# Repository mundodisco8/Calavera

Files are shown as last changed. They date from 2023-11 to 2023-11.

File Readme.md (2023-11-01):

# Calavera Badge

We wanted to run a "lunch and learn" day at the company I used to work about soldering. I always liked [Protopic's Day of the Geek Soldering Badge](https://www.proto-pic.co.uk/day-of-the-geek-badge/), but it only turns two LEDs on when you slide the battery, and I thought that my mates would need a bit more than a couple of LEDs to be able to say that they know how to solder, so I thought on modifying. I checked around but it seems the project is not open source, so I decided to ~~blatantly copy~~ get inspired by them.

<p float="center">
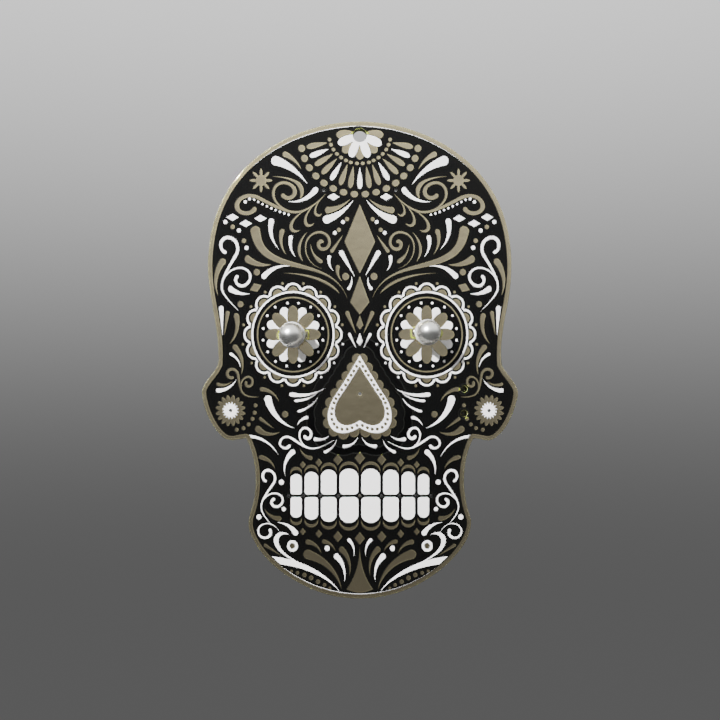
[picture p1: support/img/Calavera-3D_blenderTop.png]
  
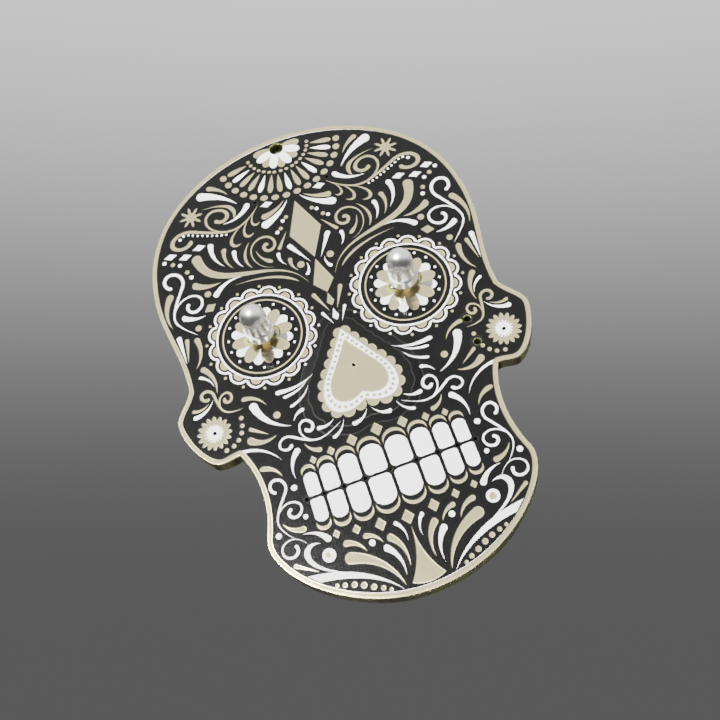
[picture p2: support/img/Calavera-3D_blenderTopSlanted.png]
  
</p>

<p float="center">
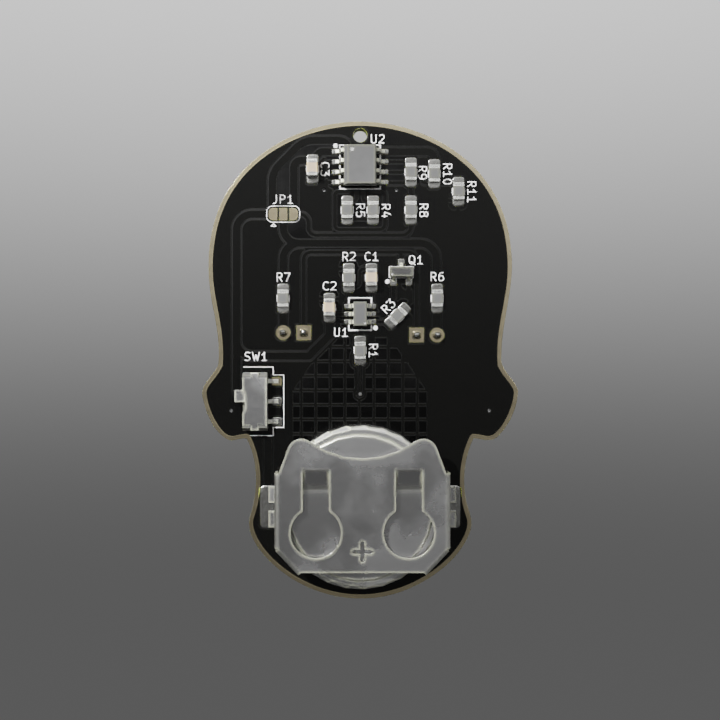
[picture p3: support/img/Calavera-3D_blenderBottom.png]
  
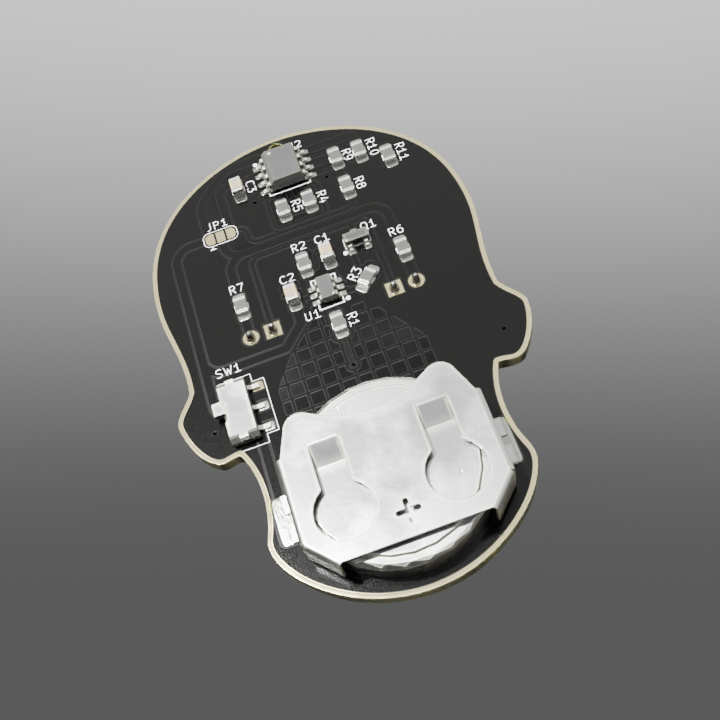
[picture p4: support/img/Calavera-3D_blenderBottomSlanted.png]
  
</p>

So here I was, thinking how to improve it, if I should go nuts or keep it simple. Danny, what should I do? should I go simple?

Danny says nope!

As I wanted to do a bit more, I decided to add two features:

* A way to turn it on and off. I thought adding a slider switch (and that would be a terrific idea in any case). I had never experimented with cap touch, so I thought in giving it a go.
* Add a "breathe" effect to the LEDs.

The schematic includes instructions on pretty much everything, so I recommend checking it. You can choose how challenging you want it to be, from "slide battery to get LEDs on" to "cap touch with breathe effect" and all the possibilities in between.

Turns out the badge is a bit overkill. It took me around 30 minutes to do one, and a colleague that has never soldered took something around 2-3h to finish it.

ups!

I was testing Cadlab when I was doing this project, you can view this project [here](https://cadlab.io/project/2044).

## Variants

I wanted to experiment with plated PCB borders. It gives it a very nice touch, but they are expensive, so you might want to make a cheaper version. There are two "footprints" for the soldermask "part", so you can choose to have the plated border or not. You might want to run the "Border" variant even without plated borders to get a nice copper outline, too. In any case, this board is yelling to be finished in ENIG, so please expend some money on that. Is not that expensive.

## The support folder

You can find the original SVG used for the art, as well as some SVGs I used to

## Known Issues / To Do:

* Tweak the cap touch pad / circuitry. Right now the cap touch feature is not very reliable. The values are the standard ones provided in the datasheet. A bit of experimenting could make it more reliable, but who has time for that, right?

## Acknowledgements

* [Terayza](https://github.com/Terayza) for her invaluable help.
* Protopic for doing their Day of the Geek soldering badge. Theirs is infinitely nicer than mine.
* The graphic on the top silkscreen / soldermask is taken from [Freepik](www.freepik.com).
* [The SVG2Shenzhen plugin.](https://github.com/badgeek/svg2shenzhen)
* My mate Danny DV, for being so nice and lending his image for this readme.

## Changelog

### v0.3.1-RC1 - 30th October 2023

* Moved the project to KiCad 7, and took the opportunity to tweak some footprints and the art.
* Made the touch area a bit bigger.

### v0.3.0 (untested, never produced) - 28th October 2022

Slightly improved version.

* Changed the double NMOS for a single one. Package is the "same" than v0.2.0 (SOT23), but having only 3 pins should make it way simpler to solder. We don't drive current, so we don't need two transistors.
* Cleaned the track layout
* Added a switch so you can fully turn it off when not in use.
* Added a couple of good practices from [ST's AN4312](https://www.st.com/resource/en/application_note/dm00087990-design-with-surface-sensors-for-touch-sensing-applications-on-mcus-stmicroelectronics.pdf). Hatched the ground below the pad and made its trace to the sensor thinner. Planes connected to ground which increases the parasitic capacitance on the cap sensor (bad) but it's better than a floating plane as it was before (worse).

### v0.2.0 (untested, never produced) - 10th January 2020

Slightly improved version.

* Cleaned the folder structure. Now all the parts are in the same library, and all the 3D models are relatively referenced to the project path.
* Changed the transistor to a SOT23. Should be easier to solder.
* Increased the track width.
* Made the border slightly thinner, I think? I don't remember. Probably.
* Isolated the ground plane from the copper pour, because I suspect that it will improve the touch response, but I have no idea if it will work.

### v0.1.0 - 23rd September 2019

First version of this board. It works 💃🎉🚀🦼! But not very well 💣🥦...

* Cap touch is hit and miss. I think that the fact that the border is exposed and tied to ground makes that when you hold it, you mess with the electric field. The whole subcircuit might need a makeover.
* The tracks are very thin and can be ripped up by a young padawan.
* The transistor footprint is devilishly difficult to solder even for an experienced Jedi.

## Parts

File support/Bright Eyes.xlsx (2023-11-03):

 |  |  |  | V | 3 | 2.5
R1 | 180000 | 180000 | 200000 | Vtpp | 0.4390243902 | 0.3658536585
R2 | 1200 | 1470 | 1500 | Vttmax | 2.6 | 2.2
R3 | 8200 | 10000 | 10000 | Vtmin | 2.182409342 | 1.782089086
C1 | 0.000022 | 0.000022 | 0.000022
V Bias ratio | 0.80 | 0.80 | 0.80
Vbias @3 | 2.40 | 2.40 | 2.40
Vbias @2.5 | 2.00 | 2.00 | 2.00
Freq | 0.431 | 0.429 | 0.379
Trise | 0.46 | 0.46 | 0.53
Tfall | 1.86 | 1.86 | 2.11
Rbias1 | 2490 | Ratio | 0.80
RBias2 | 10000

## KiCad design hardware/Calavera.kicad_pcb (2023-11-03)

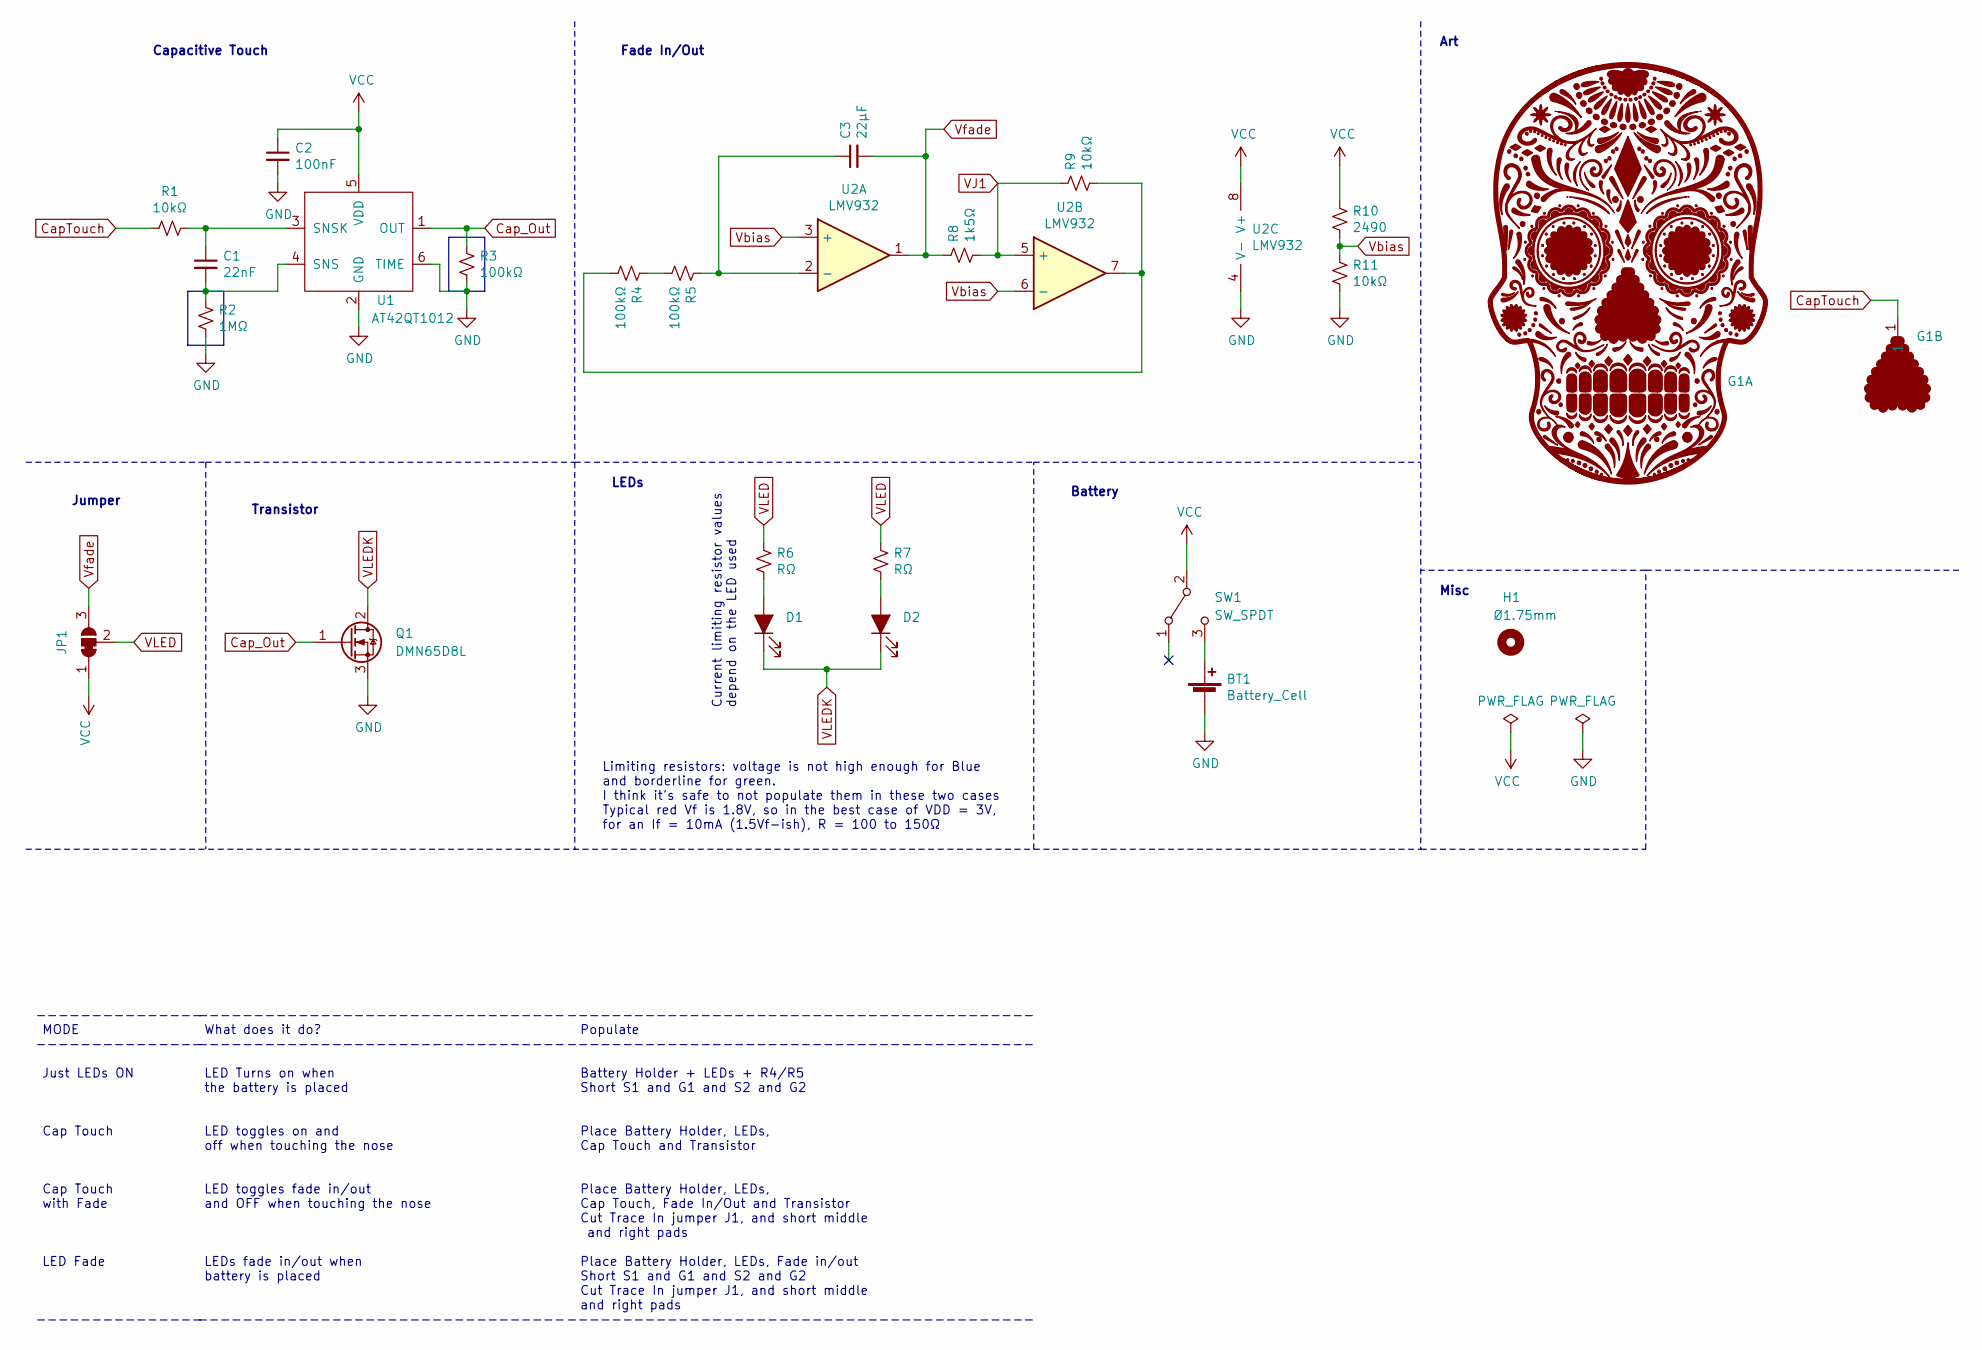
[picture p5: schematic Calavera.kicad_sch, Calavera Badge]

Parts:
BT1: Battery_Cell; CR2032_Keystone_3024; MPN 3034; Digikey PN 36-3034-ND
C1: 22nF; 0805-C_Handsolder; Tolerance X7R; MPN 885342207011; Digikey PN 732-12080-1-ND
C2: 100nF; 0805-C_Handsolder; Tolerance X7R; MPN CL21B104KBCNNNC; Digikey PN 1276-1003-1-ND
C3: 22μF; 0805-C_Handsolder; Tolerance X7R; MPN GRM21BZ71A226ME15L; Digikey PN 490-GRM21BZ71A226ME15LCT-ND
D1, D2: LED_Small_ALT; LED_D3.0mm_ThroughHole; MPN N/A; Digikey PN N/A
G1: Calavera_Art; MPN N/A; Digikey PN N/A
H1: Ø1.75mm; MountingHole_1.75mm; MPN N/A; Digikey PN N/A
JP1: SolderJumper_3_Bridged12; SolderJumper-3_P1.3mm_Bridged12_RoundedPad1.0x1.5mm; MPN N/A; Digikey PN N/A
Q1: DMN65D8L; SOT-23_NMOS_DMN65D8L; MPN DMN65D8L; Digikey PN DMN65D8L-7DICT-ND
R1, R9, R11: 10kΩ; 0805-R_Handsolder; Tolerance ±1%, 1/8W; MPN CR0805-FX-1002ELF; Digikey PN CR0805-FX-1002ELFCT-ND
R2: 1MΩ; 0805-R_Handsolder; Tolerance ±1%, 1/8W; MPN CR0805-FX-1004ELF; Digikey PN CR0805-FX-1004ELFCT-ND
R3, R4, R5: 100kΩ; 0805-R_Handsolder; Tolerance ±1%, 1/8W; MPN CR0805-FX-1003ELF; Digikey PN CR0805-FX-1003ELFCT-ND
R6, R7: RΩ; 0805-R_Handsolder; MPN N/A; Digikey PN N/A
R8: 1k5Ω; 0805-R_Handsolder; Tolerance ±1%, 1/8W; MPN CR0805-FX-1501ELF; Digikey PN CR0805-FX-1501ELFCT-ND
R10: 2490; 0805-R_Handsolder; Tolerance ±1%, 1/8W; MPN CR0805-FX-2491ELF; Digikey PN CR0805-FX-2491ELFCT-ND
SW1: SW_SPDT; Slider_Switch_C&K_AYZ0102AGRLC_SPDT_RightAngle; MPN AYZ0102AGRLC; Digikey PN 401-2012-1-ND
U1: AT42QT1012; SOT23-6-AT42QT1012; MPN AT42QT1012-TSHR; Digikey PN 401-2012-1-ND
U2: LMV932; SOIC-8_Dual_OpAmp_Handsolder; MPN LMV932DR2G; Digikey PN LMV932DR2GOSCT-ND

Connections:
CapTouch: G1.1, R1.2
Cap_Out: Q1.1 (G), R3.1, U1.1 (OUT)
GND: BT1.-, C2.2, Q1.3 (S), R2.2, R3.2, R11.2, U1.2 (GND), U1.6 (TIME), U2.4 (V-)
unnamed: D1.2 (A), R6.2
unnamed: D2.2 (A), R7.2
unnamed: R4.1, R5.2
unnamed: R4.2, R9.2, U2.7
unnamed: BT1.+, SW1.3 (C)
unnamed: C1.2, R2.1, U1.4 (SNS)
unnamed: C1.1, R1.1, U1.3 (SNSK)
unnamed: C3.1, R5.1, U2.2 (-)
VCC: C2.1, JP1.1 (A), R10.1, SW1.2 (B), U1.5 (VDD), U2.8 (V+)
VJ1: R8.2, R9.1, U2.5 (+)
VLED: JP1.2 (C), R6.1, R7.1
VLEDK: D1.1 (K), D2.1 (K), Q1.2 (D)
Vbias: R10.2, R11.1, U2.3 (+), U2.6 (-)
Vfade: C3.2, JP1.3 (B), R8.1, U2.1

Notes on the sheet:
Battery
--------------- MODE --------------- Just LEDs ON Cap Touch Cap Touch with Fade LED Fade ---------------
Capacitive Touch
Misc
Current limiting resistor values depend on the LED used
Jumper
Fade In/Out
Transistor
Limiting resistors: voltage is not high enough for Blue and borderline for green. I think it's safe to not populate them in these two cases Typical red Vf is 1.8V, so in the best case of VDD = 3V, for an If = 10mA (1.5Vf-ish), R = 100 to 150Ω
--------------------------------- What does it do? --------------------------------- LED Turns on when the battery is placed LED toggles on and off when touching the nose LED toggles fade in/out and OFF when touching the nose LEDs fade in/out when battery is placed ---------------------------------
------------------------------------------ Populate ------------------------------------------ Battery Holder + LEDs + R4/R5 Short S1 and G1 and S2 and G2 Place Battery Holder, LEDs, Cap Touch and Transistor Place Battery Holder, LEDs, Cap Touch, Fade In/Out and Transistor Cut Trace In jumper J1, a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
LEDs
Art

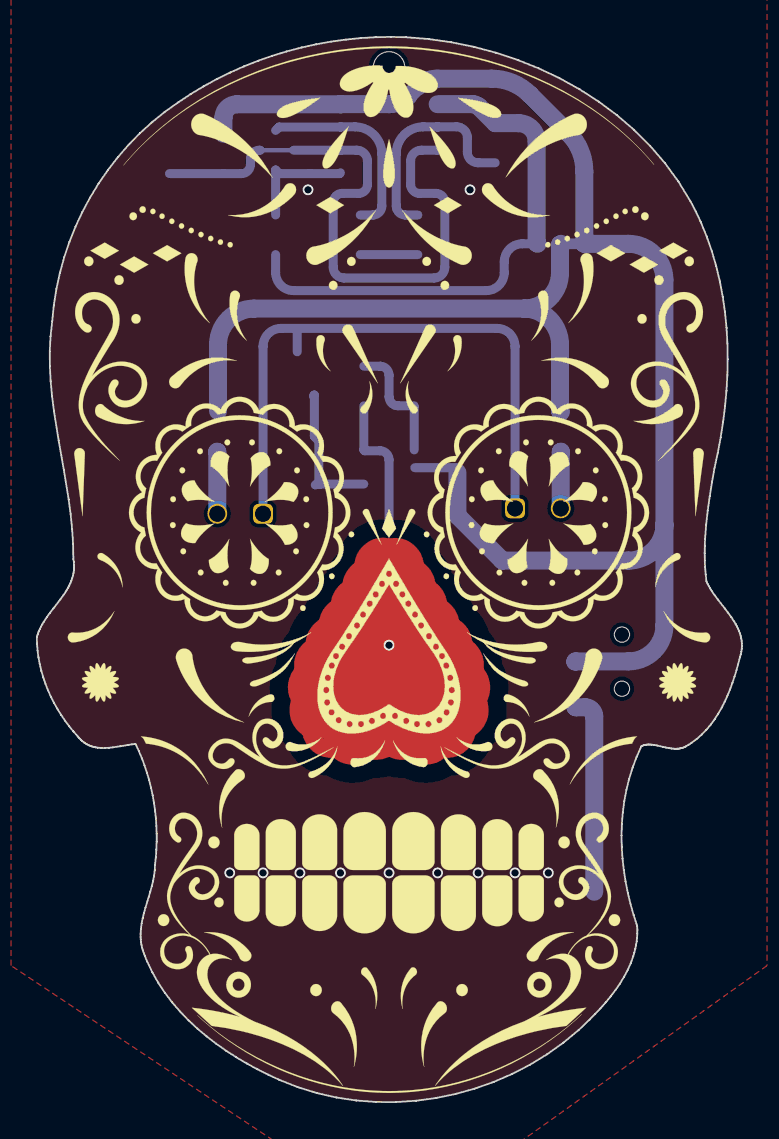
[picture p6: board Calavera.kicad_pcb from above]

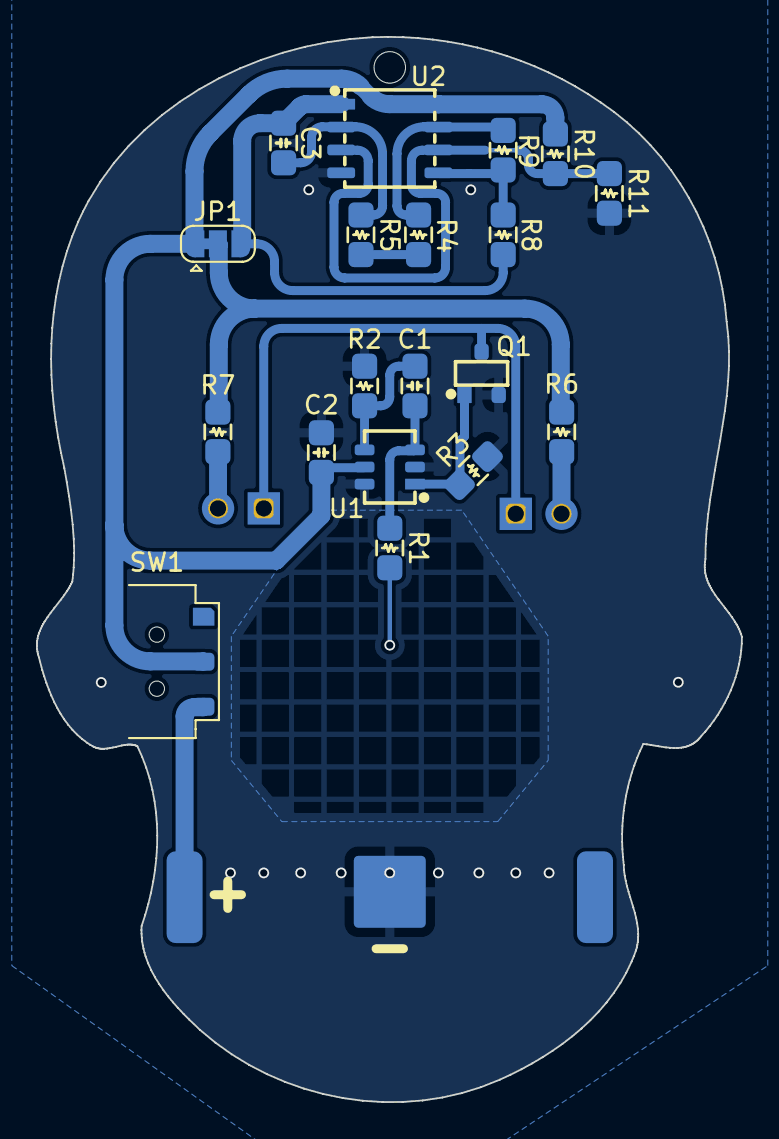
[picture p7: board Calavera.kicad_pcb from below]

Board: 2 copper layers, 39.2 x 59.2 mm, 24 parts (20 on the bottom side), 17 nets.

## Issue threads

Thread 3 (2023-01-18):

Redo Silkscreen

mundodisco8, 2023-01-18:
And also substract the mask from it so we don't have a thousand silkscreen over copper errors

Closed 2023-10-30.

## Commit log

2019-08-19 First commit of project files. The project is ready for manufacture, but there's still some cleaning to do
    [Calavera.kicad_pcb, Calavera.sch]
2019-08-20 Added Silk, Mask and Edge as schematic symbols Updated silk and mask, as they got misaligned Added silk to the nose pad
    [Calavera.kicad_pcb, Calavera.sch]
2019-08-22 Added an exposed outline around the board (and extended the copper plane to the PCB edge) to try to get the side plated too. Changed the Silk and Soldermask parts for this change, and also corrected 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
    [Calavera.kicad_pcb]
2019-08-23 Tweaked a couple of things on the PCB as the exposed copper on the edge of the PCB could make soldering a tad difficult
    [Calavera.kicad_pcb]
2019-08-23 Removed border plating and exposed border Sadly, it increased the cost x3!
    [Calavera.kicad_pcb]
2019-09-23 v1.0 - Manufactured for the lunch and learn
    [Battery Holder - CR2032 - Multicomp MP000357 v5.step, Battery Holder - CR2032 Clipped - Multicomp MP000357 v2.step, Bright Eyes.xlsx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]
2019-09-23 Better assembly drawings
    [Calavera.kicad_pcb]
2019-10-18 Added BoM xml
    [Calavera_bom.xlsx]
2020-01-09 Made tracks thicker, as they are easier to rip when overheat than I thought they would be
    [Calavera.kicad_pcb, Calavera.sch]
2020-01-09 Removed the Jumpers as they are not needed
    [Calavera.kicad_pcb, Calavera.sch]
2020-01-10 Changed the transistor footprint to a SOT23 as it was very tricky to solder.
    [Calavera.kicad_pcb, Calavera.sch]
2020-01-10 Put everything on a single library, and the 3D models are now relative to the project path
    [Calavera.kicad_pcb, Calavera.sch]
2020-01-10 Cleaning here and there
    [Calavera.kicad_pcb, Calavera.sch]
2020-01-10 Simple inline orb that does gerbers and positions
2020-01-13 Bumped orb version to fix an issue with gerbers not being generated
2020-01-14 Generate BoM
    [BoM_Template.xlsx]
2022-10-27 Updated To KiCad6
    [Calavera.kicad_pcb, Calavera.kicad_sch, Calavera.sch]
2022-10-28 v0.3.0 see changelog for details
    [Calavera.kicad_pcb, Calavera.kicad_sch]
2023-01-17 Cap touch area is bigger. Added some vias to connect both planes
    [Calavera.kicad_pcb]
2023-01-18 Added KiBot as CICD and removed CircleCI Fixed some DRC/ERC errors and tweaked the files so KiBot accepts them and generates artifacts from them
    [Calavera.kicad_pcb, Calavera.kicad_sch]
2023-01-18 Final tweak, gerbers are uploaded as a separate file
2023-10-27 Small edit of the Art. Small changes here and there to account for new DRCs in KiCad 7
    [Calavera.kicad_pcb, Calavera.kicad_sch]
2023-10-27 Hand tweaks to the art to avoid most of the ERC errors
    [Calavera.kicad_pcb, Calavera.kicad_sch]
2023-10-30 Tweaks on the project for KiBot
    [Calavera.kicad_pcb, Calavera.kicad_sch]
2023-10-31 Put some sense and changed resistor values to reduce the number of individual parts Removed ignored files and renamed a folder
    [BoM_Template.xlsx, Bright Eyes.xlsx, Calavera.kicad_sch]
2023-10-31 Simplified the values of the resistors * Added a new resistor * Moved tracks around * Added two vias to get GND to the bottom copper in an isolated island * Cleaned fabrication
    [Calavera.kicad_pcb]
2023-11-01 More Fab cleaning
    [Calavera.kicad_pcb]
2023-11-03 3D model behaves again
    [Bright Eyes.xlsx, Calavera.kicad_pcb, Calavera.kicad_sch]
